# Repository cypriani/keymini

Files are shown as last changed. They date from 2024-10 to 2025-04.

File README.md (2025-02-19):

# Keymini, a minimalist ergonomic keyboard

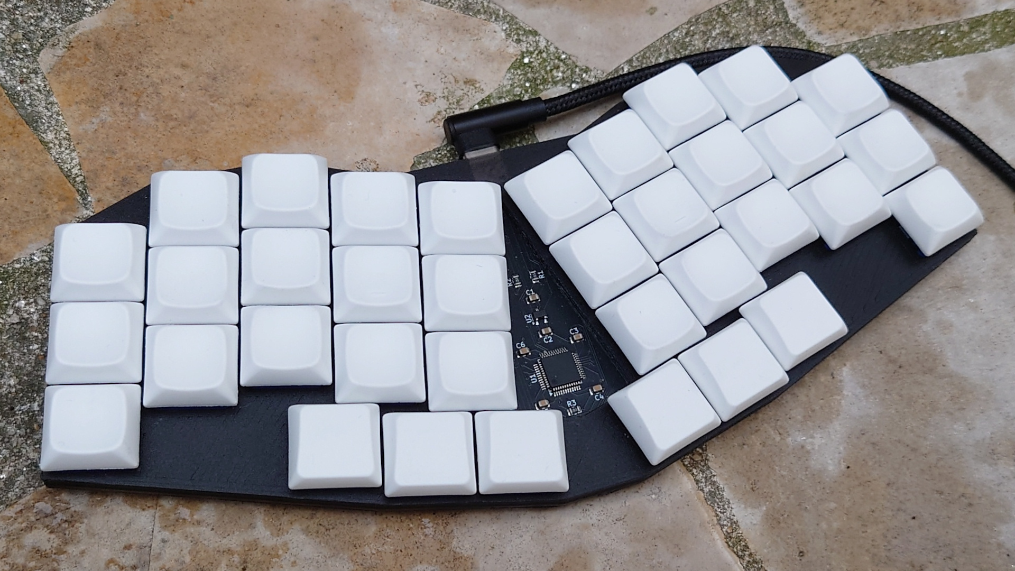
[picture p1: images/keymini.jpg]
Keymini


> Perfection is achieved, not when there is nothing more to add, but
> when there is nothing left to take away. ― Antoine de Saint-Exupéry

## Presentation

Keymini is a monoblock ergonomic keyboard with 36 keys. It is as low as
possible (with Kailh Choc v1 switches). As it is flat on the underside,
it can be used placed on a laptop keyboard, without actuating the
laptop keyboard keys.

Keymini is a minimalist keyboard in a lot of way:
* Only a keyboard, no LED, no rotary encoder, no screen, not split, no
  hotswap… Just USB-C connector and keys.
* Minimal size, entering in a C5/6 envelope (3 fold A4) or a Nintendo
  Switch Lite case.
* Minimal number of keys, at 36, as popularized by
  [Miryoku](https://github.com/manna-harbour/miryoku).
* Minimal keyspacing, following the classical "choc spacing."
* Minimal height, with the switch plate at 5.8 mm from the desk.
* Minimal number of component, with only 2 extended parts for PCB
  assembly by JLCPCB.
* Minimalistic style, with no decoration, simple hull countour.
* Minimalist license (MIT) for an opensource keyboard.

Inspirations:
* My previous designs, in particular
  [KeySeeBee](https://github.com/TeXitoi/keyseebee) for the components
  and the fat plate, and
  [Keyberon-f4](https://github.com/TeXitoi/keyberon-f4) for
  experiencing with the key placement and unibody shape.
* [Ferris](https://github.com/pierrechevalier83/ferris) for the
  stagger and the diode placement..
* [3W6](https://github.com/weteor/3W6) for the "too fat plate" design
  idea, and gluing something directly on the back of the PCB.

## Other pages to see

To see more photos, see the [gallery](GALLERY.md).

You can look at the [build guide](BUILDING.md), to see how it is
constructed, and to make your own!

For instructions on the PCB manufacturing, see the [gerbers
directory](pcb/gerbers/).

For information on building and flashing the firmware, see the
[firmware directory](firmware/).

For information on the default layout, see the [layout page](LAYOUT.md).

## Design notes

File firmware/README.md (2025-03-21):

# Keymini Rust firmware

Install the complete toolchain and utils:

```shell
curl https://sh.rustup.rs -sSf | sh
# restart terminal to update the environment
rustup target add thumbv6m-none-eabi
rustup component add llvm-tools-preview
cargo install cargo-binutils
sudo apt-get install dfu-util
```

Compile:

```shell
cd firmware
cargo objcopy --bin keymini --release -- -O binary firmware.bin
```

To flash using dfu-util, launch it with:
```shell
dfu-util -w -d 0483:df11 -a 0 -s 0x08000000:leave -D firmware.bin
```

Then, put the board in DFU mode by:
 * Putting the keyboard in DFU mode as defined in the firmware. By
   default, it’s the leftmost key on the function layer. So, press
   simultaneously the 2 middle thumb keys, and then tap the leftmost
   thumb key.
 * Or (for the first time, or in case of buggy firmware) by shorting
   the 2 pads under the board (with a piece of aluminium foil for
   example, pressing hard) and plug USB while doing the connection.

Upload should begin as soon as the computer detects the board in
DFU mode.

The first time, if the write fail, your flash might be protected. To
unprotect:

```shell
dfu-util -d 0483:df11 -a 0 -s 0x08000000:force:unprotect -D firmware.bin
```

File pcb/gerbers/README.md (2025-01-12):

# Instructions

Choose a version, go to the corresponding directory.

Go to [JLCPCB](https://jlcpcb.com/). Upload the zip file as "gerber
file". Choose the PCB color and surface finish. The other options
should be OK as default.

Activate PCB Assembly. Assemble top side, economic. Select "tooling
holes: added by JLCPCB. The other options should be OK as default.

Add "boom.csv" as BOM file and "keymini-top-pos.csv" as CLP file.

Check that the components are found and in stock. The USB-C connector
has a standard footprint, so another reference can be used. Also, you
can use a STM32F072C8T6 if the CB variant is not available (less
flash, but enough for a keyboard).

Check the position of the USB-C connector. Check the direction of the
diodes (the bar should be on the left). Check that the LDO (the 3 pin
chip) is correctly placed. Check that the MCU is correctly placed,
with the marked pin aligned with the mark on the silkscreen (bottom
left).

2024-11-04, I payed 63.62€ including tax and shipping to France using
"Global Standard Direct Line".

# Change log

## v0.2 (2025-01-12)

* add copper pur on the top
* remove SWD connector

Manufactured at JLCPCB. Fully fonctionnal. Some PCB are lightly
warped, some are perfectly flat.

## v0.1 (2024-11-04)

Manufactured SMT.

Sent to manufacturing at JLCPCB. Fully functionnal. The PCB are
warped, maybe because of the ground filling only on one side. This
warping makes an anoying balance of the keyboard when pushing on the
thumb keys. A workaround is to insert a spacer on the back between the
silicone sheet and the PCB under the BOOT connector.

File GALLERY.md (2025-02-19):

# Gallery

## v0.1, first prototype, gChoc switchs, ChocFox CFX keycaps, black PLA plate

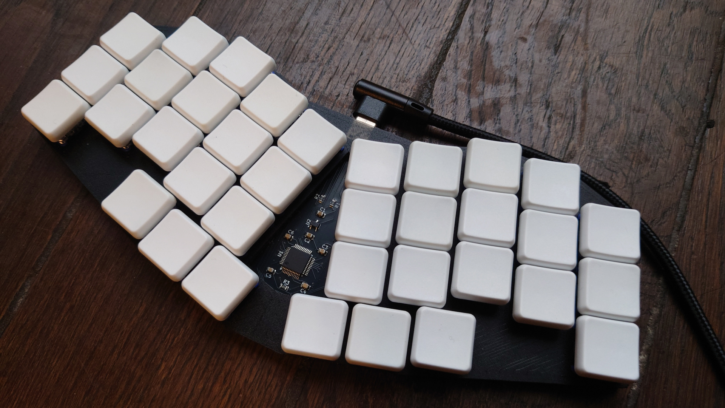
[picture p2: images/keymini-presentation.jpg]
presentation


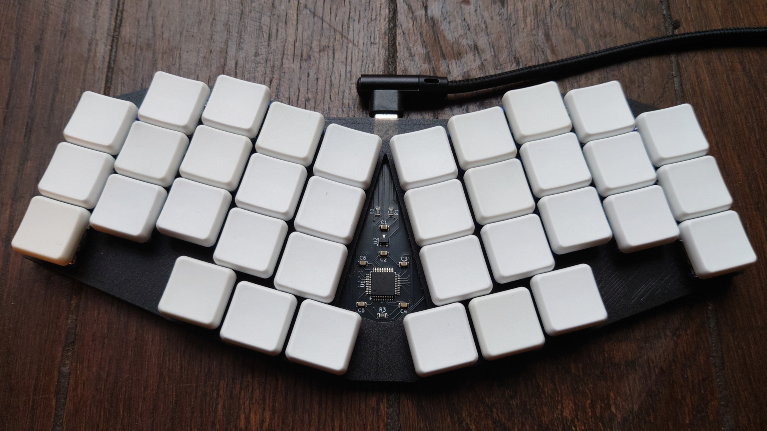
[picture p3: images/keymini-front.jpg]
front


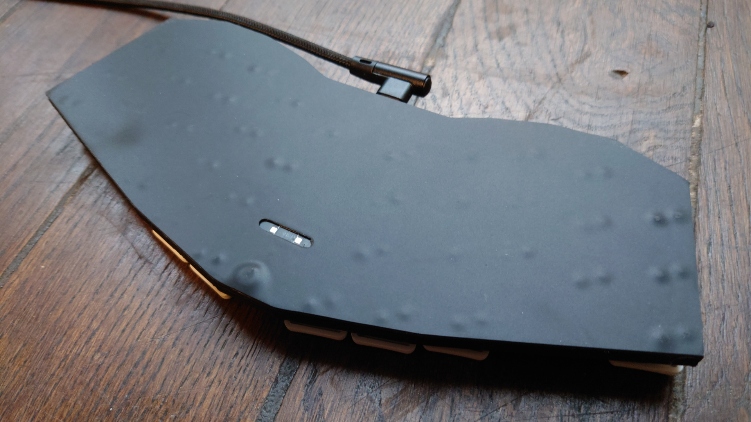
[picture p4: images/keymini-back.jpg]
back


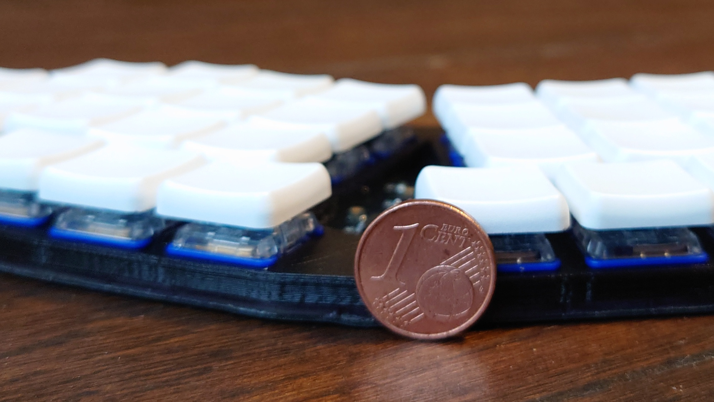
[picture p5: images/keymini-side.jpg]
side


## v0.1, Twilight switches, DDC keycaps, red PLA plate masking the components

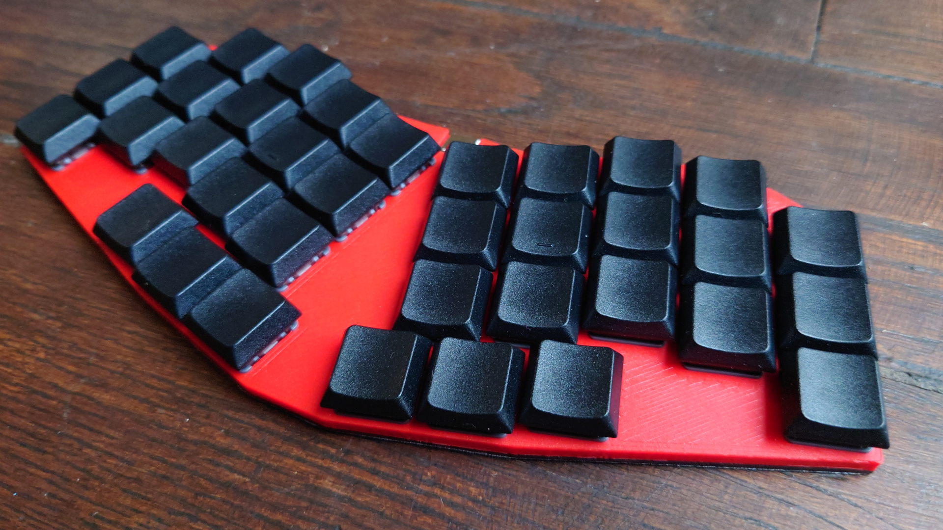
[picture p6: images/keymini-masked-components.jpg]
masked-components


## v0.2, Noctural switches, KLP Lamé normal on SLS nylon, colorless matte glazed oak plate

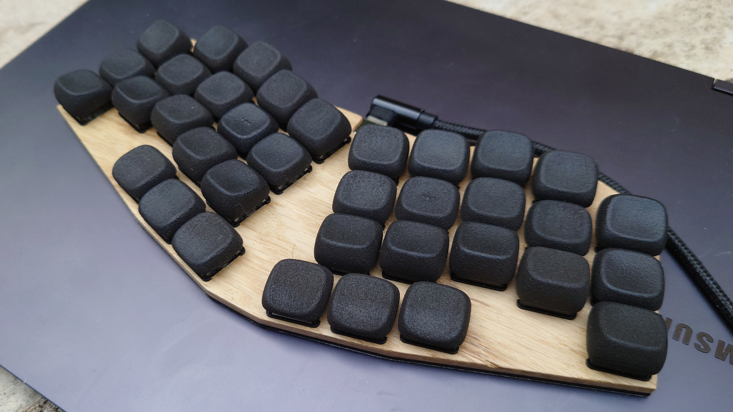
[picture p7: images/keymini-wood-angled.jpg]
angled


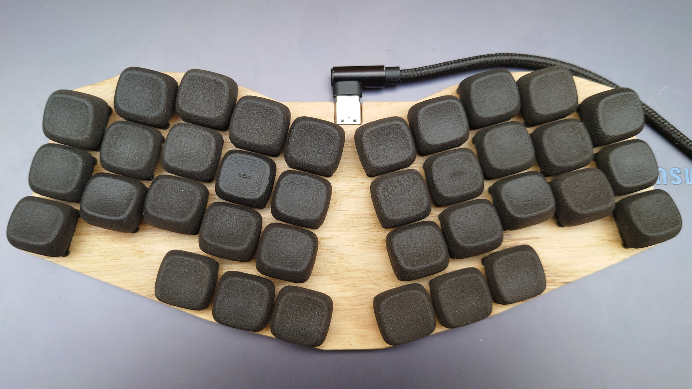
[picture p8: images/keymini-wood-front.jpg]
front


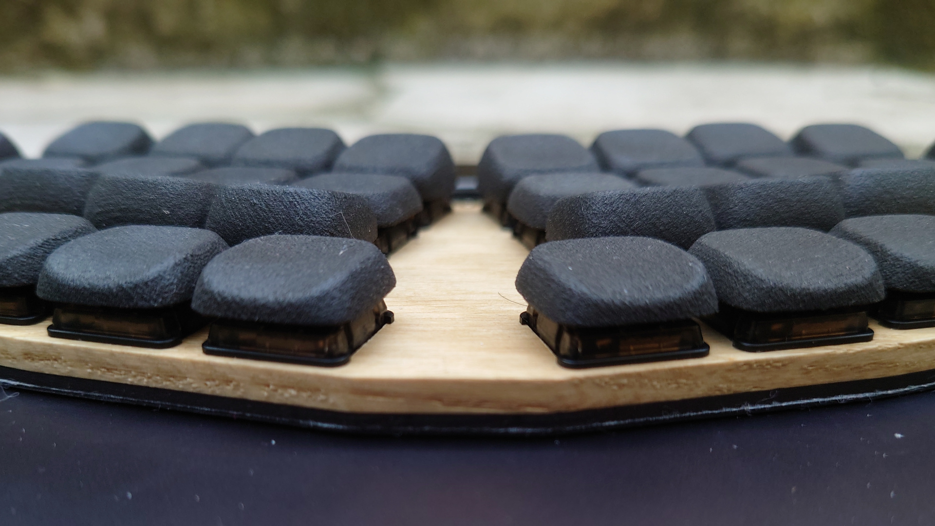
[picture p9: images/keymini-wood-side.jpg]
side


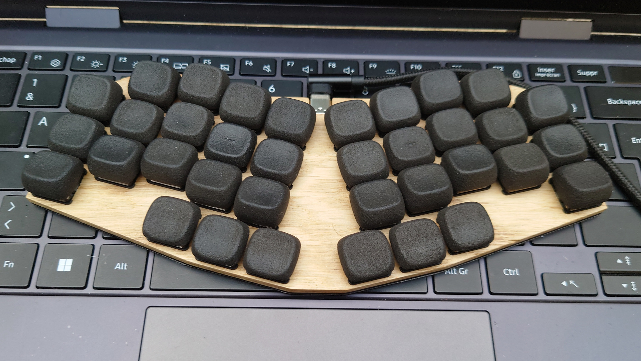
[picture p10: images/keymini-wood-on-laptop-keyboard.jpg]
on laptop keyboard


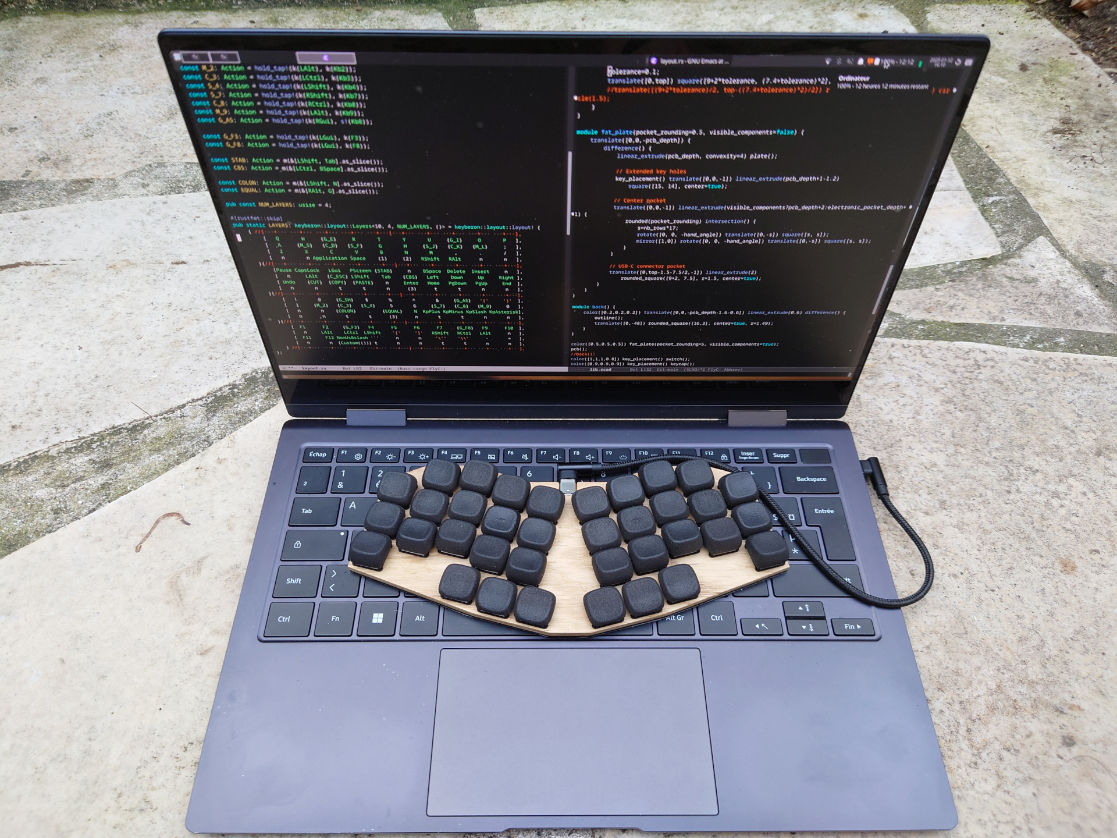
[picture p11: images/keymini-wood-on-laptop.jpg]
on laptop


## v0.2, Noctural switches, MBK keycaps, built by Louis

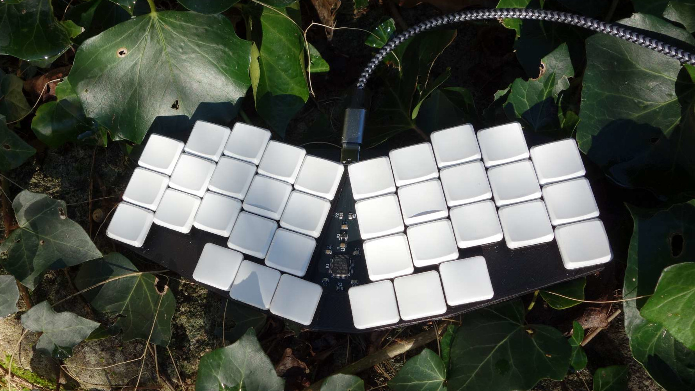
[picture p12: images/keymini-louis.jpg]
Louis’ Keymini


## v0.2, Noctural switches, LDSA keycaps, purple with alumine PLA plate

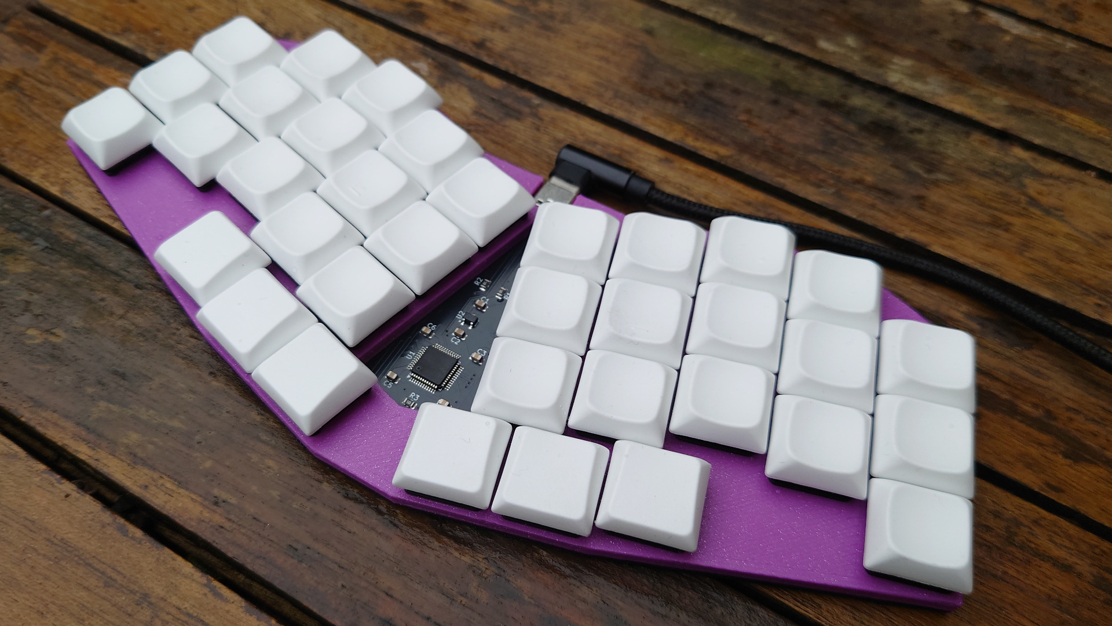
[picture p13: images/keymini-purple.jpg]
purple


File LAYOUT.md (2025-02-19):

# Layout

As of the time of writing, I use a 4 layer layout, and the
[ergo‑l](https://ergol.org) layout, that provide an optimized symbol
layer on AltGr, plus additional french characters on a custom dead key
(the 1DK, noted ★). So on the first layer, top right character are
accessible after typing ★, while bottom right characters are
accessible while pressing AltGr.

The Nav layer, accessible with the left radial thumb key, provides
navigation and editing functionalities. Notably, Enter is available on
this layer. The "special" keys, as Escape, Insert… are placed
logically corresponding to the alpha layer (Escape at E, Insert above
I…).

The Num layer, accessible with the right radial thumb key, privides the
num row on the home row, the shifted num row on the top row, and
numerical related symbols on the bottom row, placed in a similar
position than on the other layers.

Finally, the Function layer, accessible with the 2 radial thumb keys
pressed at the same time, provides the function keys.

Home Row Mods are available at the same place on all layers (except
the right part of the Nav layer, to not interfere with
navigation). Thanks to this, I don’t have to think about the order
between layers and mods, and cords them in practice.

Shift has its dedicated thumb key for typing text, and is also
available as home row mod for mods combos. GUI (the Windows key, that
I mainly use for window manager shortcuts) is on the 2 upper middle
finger keys, as they are not used with the other modifiers, except
Shift. Pinky doesn’t have HRM as it is unconfortable to maintain
pressed.

Of course, all of this is my layout, and I encourage you to tweek
yours. My main inspiration was
[Miryoku](https://github.com/manna-harbour/miryoku). Another great
resource is [Arsenik](https://github.com/OneDeadKey/arsenik).

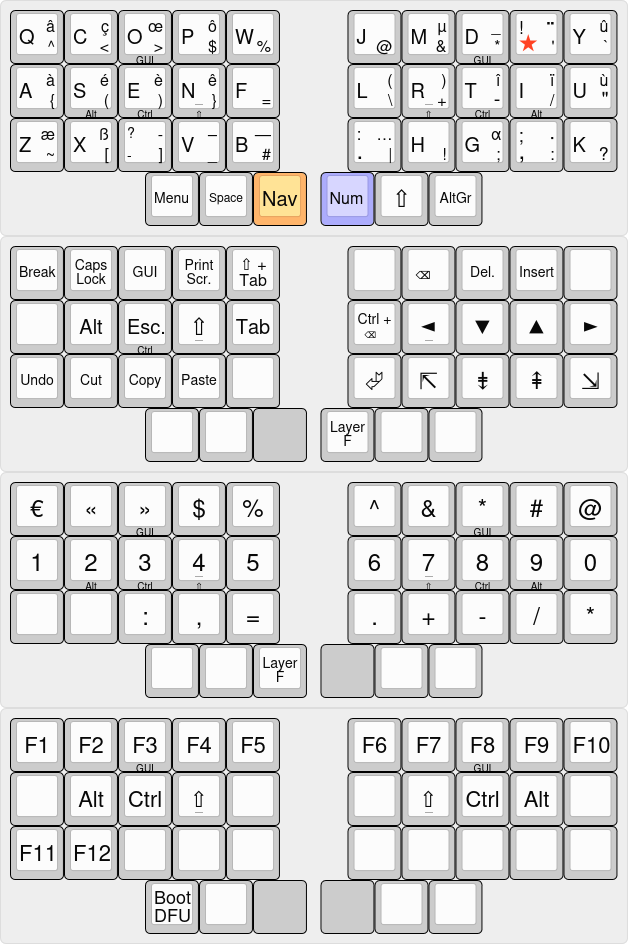
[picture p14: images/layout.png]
Layout


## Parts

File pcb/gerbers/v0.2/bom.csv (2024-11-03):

Designator | Footprint | Quantity | Designation | LCSC Part Number
C2,C1 | C_0805_2012Metric | 2 | 1µF | C28323
D2A1,D4D1,D2H1,D3H1,D4E1,D4G1,D2G1,D1I1,D2B1,D2F1,D3C1,D3B1,D1A1,D4C1,D1B1,D1C1,D1J1,D3E1,D3D1,D2E1,D1E1,D2I1,D1F1,D1H1,D3I1,D3J1,D2C1,D3F1,D2D1,D3G1,D3A1,D4H1,D2J1,D1D1,D4F1,D1G1 | D_SOD-323 | 36 | 1N4148WS | C2128
C4,C3,C6,C5 | C_0805_2012Metric | 4 | 100nF | C28233
R2,R1,R3 | R_0805_2012Metric | 3 | 5.1k | C27834
U1 | LQFP-48_7x7mm_P0.5mm | 1 | STM32F072CBT6 | C81720
J1 | USB_C_Receptacle_HRO_TYPE-C-31-M-12 | 1 | USB_C_Receptacle_USB2.0_16P | C165948
U2 | SOT-23-3 | 1 | XC6206P332MR | C5446

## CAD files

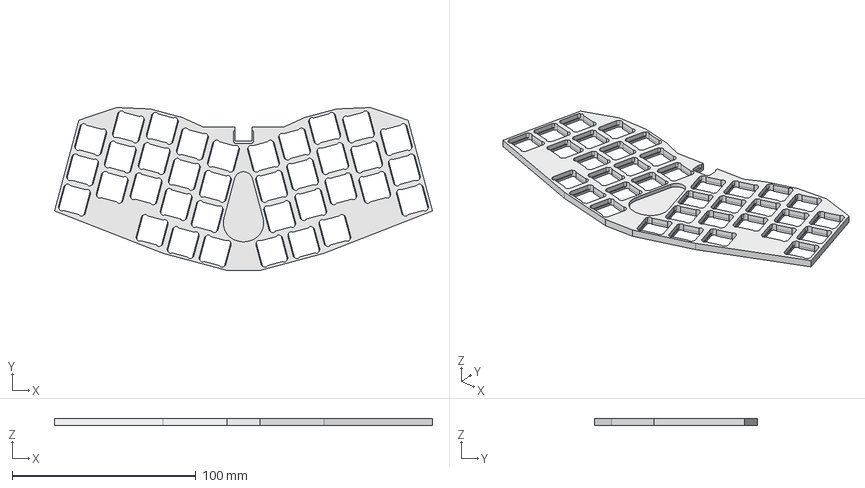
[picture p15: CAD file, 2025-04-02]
cad/fat_plate.FCStd
205.4 x 88.6 x 3.80 mm

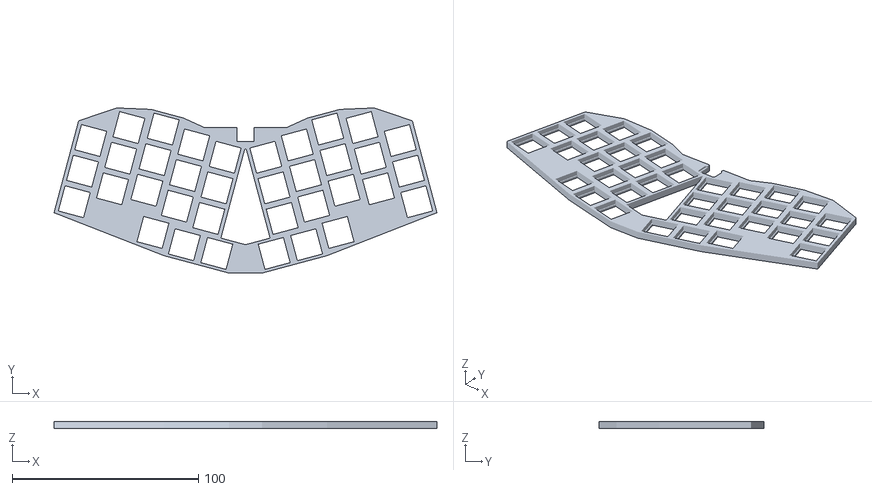
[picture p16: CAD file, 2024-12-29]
cad/fat_plate_visible_components.stl
205.4 x 88.6 x 3.80

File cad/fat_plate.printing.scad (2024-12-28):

use <lib.scad>;

rotate([0,180,0]) fat_plate(pocket_rounding=4);

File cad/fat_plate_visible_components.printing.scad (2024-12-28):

use <lib.scad>;

rotate([0,180,0]) fat_plate(visible_components=true);

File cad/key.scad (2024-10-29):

use <utils.scad>

module keycap() {
    translate([0,0,4]) hull() {
        linear_extrude(0.1) square([17.5, 16.5], center=true);
        translate([0, 0, 3]) linear_extrude(0.1) rounded_square(12, r=1.5, center=true);
    }
}

module switch() {
    translate([0,0,-2.2]) linear_extrude(3) rounded_square([13.5,13.5], r=1, center=true);
    linear_extrude(3, scale=0.8) rounded_square([15, 15], r=1, center=true);
    translate([0,0,-2.2-2.65]) cylinder(h=5, d=4);
}

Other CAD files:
cad/fat_plate-cnc_1.5mm.step
cad/plate.stl
cad/lib.scad
cad/fat_plate.stl
cad/plate.2d.scad
cad/plate.dxf
cad/utils.scad

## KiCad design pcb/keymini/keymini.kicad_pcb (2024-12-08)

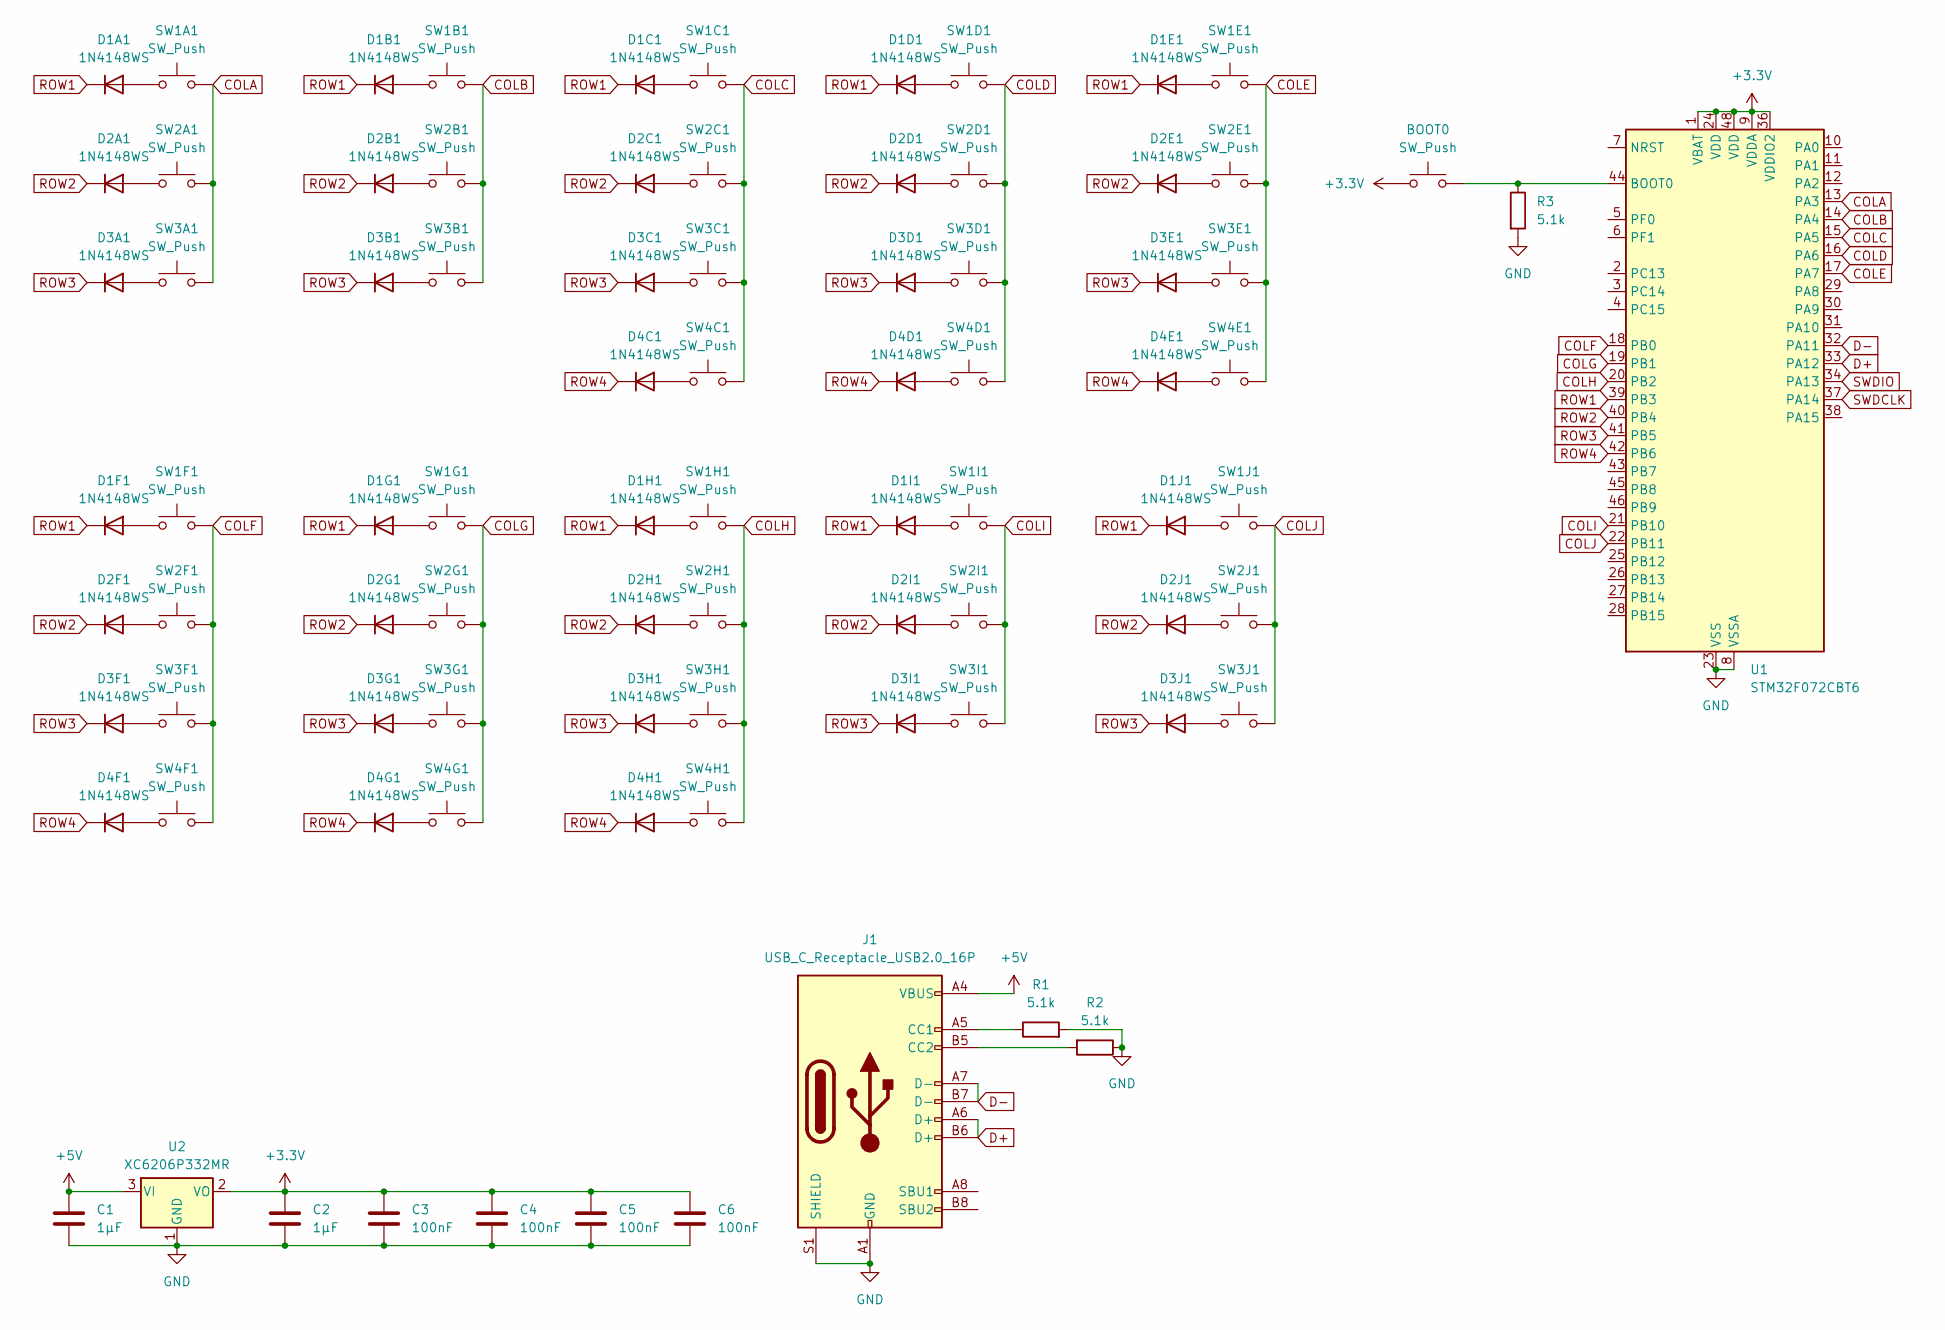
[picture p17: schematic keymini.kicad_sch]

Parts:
BOOT0: SW_Push; SW_SPST_CK_RS282G05A3
C1, C2: 1µF; C_0805_2012Metric
C3, C4, C5, C6: 100nF; C_0805_2012Metric
D1A1, D1B1, D1C1, D1D1, D1E1, D1F1, D1G1, D1H1, D1I1, D1J1, D2A1, D2B1, D2C1, D2D1, D2E1, D2F1, D2G1, D2H1, D2I1, D2J1, D3A1, D3B1, D3C1, D3D1, D3E1, D3F1, D3G1, D3H1, D3I1, D3J1, D4C1, D4D1, D4E1, D4F1, D4G1, D4H1: 1N4148WS; D_SOD-323
J1: USB_C_Receptacle_USB2.0_16P; USB_C_Receptacle_HRO_TYPE-C-31-M-12
R1, R2, R3: 5.1k; R_0805_2012Metric
SW1A1, SW1B1, SW1C1, SW1D1, SW1E1, SW1F1, SW1G1, SW1H1, SW1I1, SW1J1, SW2A1, SW2B1, SW2C1, SW2D1, SW2E1, SW2F1, SW2G1, SW2H1, SW2I1, SW2J1, SW3A1, SW3B1, SW3C1, SW3D1, SW3E1, SW3F1, SW3G1, SW3H1, SW3I1, SW3J1, SW4C1, SW4D1, SW4E1, SW4F1, SW4G1, SW4H1: SW_Push; SW_PG1350
U1: STM32F072CBT6; LQFP-48_7x7mm_P0.5mm
U2: XC6206P332MR; SOT-23-3

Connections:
+3.3V: BOOT0.1, C2.1, C3.1, C4.1, C5.1, C6.1, U1.1 (VBAT), U1.9 (VDDA), U1.24 (VDD), U1.36 (VDDIO2), U1.48 (VDD), U2.2 (VO)
+5V: C1.2, J1.A4 (VBUS), J1.A9 (VBUS), J1.B4 (VBUS), J1.B9 (VBUS), U2.3 (VI)
COLA: SW1A1.2, SW2A1.2, SW3A1.2, U1.13 (PA3)
COLB: SW1B1.2, SW2B1.2, SW3B1.2, U1.14 (PA4)
COLC: SW1C1.2, SW2C1.2, SW3C1.2, SW4C1.2, U1.15 (PA5)
COLD: SW1D1.2, SW2D1.2, SW3D1.2, SW4D1.2, U1.16 (PA6)
COLE: SW1E1.2, SW2E1.2, SW3E1.2, SW4E1.2, U1.17 (PA7)
COLF: SW1F1.2, SW2F1.2, SW3F1.2, SW4F1.2, U1.18 (PB0)
COLG: SW1G1.2, SW2G1.2, SW3G1.2, SW4G1.2, U1.19 (PB1)
COLH: SW1H1.2, SW2H1.2, SW3H1.2, SW4H1.2, U1.20 (PB2)
COLI: SW1I1.2, SW2I1.2, SW3I1.2, U1.21 (PB10)
COLJ: SW1J1.2, SW2J1.2, SW3J1.2, U1.22 (PB11)
D+: J1.A6 (D+), J1.B6 (D+), U1.33 (PA12)
D-: J1.A7 (D-), J1.B7 (D-), U1.32 (PA11)
GND: C1.1, C2.2, C3.2, C4.2, C5.2, C6.2, J1.A1 (GND), J1.A12 (GND), J1.B1 (GND), J1.B12 (GND), J1.S1 (SHIELD), R1.2, R2.1, R3.2, U1.8 (VSSA), U1.23 (VSS), U1.35 (VSS), U1.47 (VSS), U2.1 (GND)
unnamed: D1A1.2 (A), SW1A1.1
unnamed: D1B1.2 (A), SW1B1.1
unnamed: D1C1.2 (A), SW1C1.1
unnamed: D1D1.2 (A), SW1D1.1
unnamed: D1E1.2 (A), SW1E1.1
unnamed: D1F1.2 (A), SW1F1.1
unnamed: D1G1.2 (A), SW1G1.1
unnamed: D1H1.2 (A), SW1H1.1
unnamed: D1I1.2 (A), SW1I1.1
unnamed: D1J1.2 (A), SW1J1.1
unnamed: D2A1.2 (A), SW2A1.1
unnamed: D2B1.2 (A), SW2B1.1
unnamed: D2C1.2 (A), SW2C1.1
unnamed: D2D1.2 (A), SW2D1.1
unnamed: D2E1.2 (A), SW2E1.1
unnamed: D2F1.2 (A), SW2F1.1
unnamed: D2G1.2 (A), SW2G1.1
unnamed: D2H1.2 (A), SW2H1.1
unnamed: D2I1.2 (A), SW2I1.1
unnamed: D2J1.2 (A), SW2J1.1
unnamed: D3A1.2 (A), SW3A1.1
unnamed: D3B1.2 (A), SW3B1.1
unnamed: D3C1.2 (A), SW3C1.1
unnamed: D3D1.2 (A), SW3D1.1
unnamed: D3E1.2 (A), SW3E1.1
unnamed: D3F1.2 (A), SW3F1.1
unnamed: D3G1.2 (A), SW3G1.1
unnamed: D3H1.2 (A), SW3H1.1
unnamed: D3I1.2 (A), SW3I1.1
unnamed: D3J1.2 (A), SW3J1.1
unnamed: D4C1.2 (A), SW4C1.1
unnamed: D4D1.2 (A), SW4D1.1
unnamed: D4E1.2 (A), SW4E1.1
unnamed: D4F1.2 (A), SW4F1.1
unnamed: D4G1.2 (A), SW4G1.1
unnamed: D4H1.2 (A), SW4H1.1
unnamed: J1.A5 (CC1), R1.1
unnamed: J1.B5 (CC2), R2.2
unnamed: BOOT0.2, R3.1, U1.44 (BOOT0)
ROW1: D1A1.1 (K), D1B1.1 (K), D1C1.1 (K), D1D1.1 (K), D1E1.1 (K), D1F1.1 (K), D1G1.1 (K), D1H1.1 (K), D1I1.1 (K), D1J1.1 (K), U1.39 (PB3)
ROW2: D2A1.1 (K), D2B1.1 (K), D2C1.1 (K), D2D1.1 (K), D2E1.1 (K), D2F1.1 (K), D2G1.1 (K), D2H1.1 (K), D2I1.1 (K), D2J1.1 (K), U1.40 (PB4)
ROW3: D3A1.1 (K), D3B1.1 (K), D3C1.1 (K), D3D1.1 (K), D3E1.1 (K), D3F1.1 (K), D3G1.1 (K), D3H1.1 (K), D3I1.1 (K), D3J1.1 (K), U1.41 (PB5)
ROW4: D4C1.1 (K), D4D1.1 (K), D4E1.1 (K), D4F1.1 (K), D4G1.1 (K), D4H1.1 (K), U1.42 (PB6)
SWDCLK: U1.37 (PA14)
SWDIO: U1.34 (PA13)

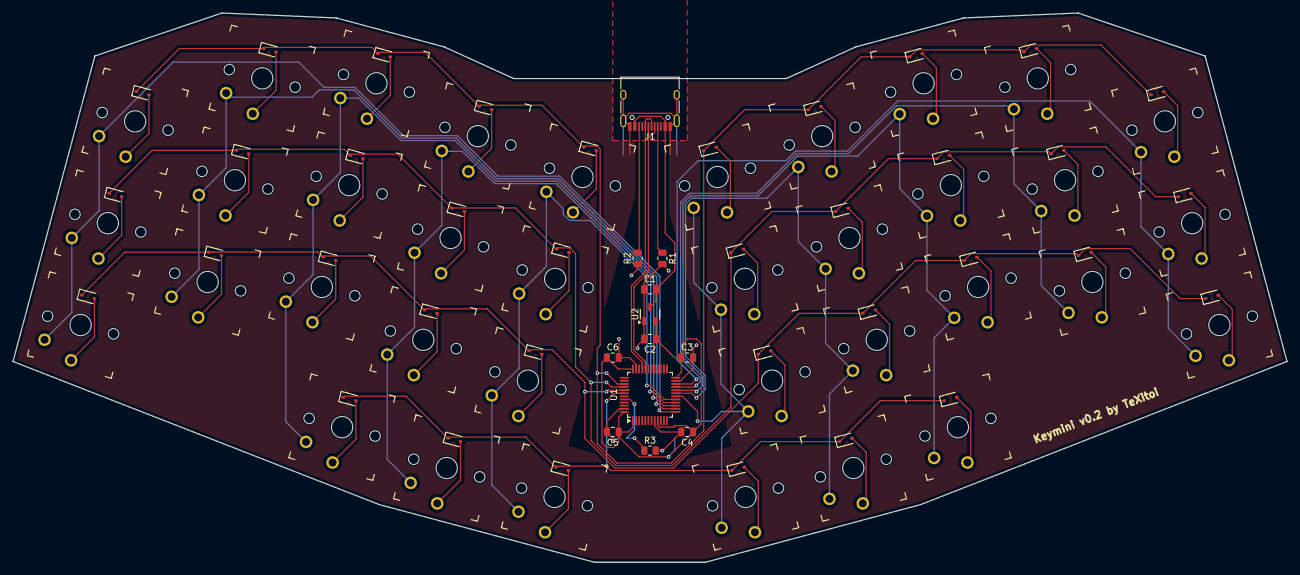
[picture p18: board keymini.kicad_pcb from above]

Board: 2 copper layers, 205.4 x 88.6 mm, 85 parts (1 on the bottom side), 58 nets.

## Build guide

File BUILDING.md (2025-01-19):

# Build guide

## Material

|Items |Quantity|
|---|---:|
|[Assembled PCB](pcb/gerbers/) | 1|
|[Fat plate](cad) | 1|
|[0.5mm self adhesive silicone sheet](https://www.aliexpress.com/item/1005003938672544.html) | 1|
|[Kailh Choc v1 switches](https://lowprokb.ca/collections/switches/products/ambients-silent-choc-switches)  | 36|
|[Choc spaced compatible keycaps](https://lowprokb.ca/collections/keycaps/products/ldsa-low-profile-blank-keycaps)|36|
|[USB-C cable](https://www.aliexpress.com/item/1005003058092715.html) | 1|
|[Solder Wire](https://www.aliexpress.com/item/1005007053733373.html) | 3g|
|Cardboard (as food packaging for example) | 20×10cm|
|Pure isopropyl alcohol or ethanol (optional) | 5mL|

|Tools                                                                                   |
|----------------------------------------------------------------------------------------|
|[Soldering kit](https://www.aliexpress.com/item/4000019437594.html)                     |
|[12mm×3mm hole punch](https://www.aliexpress.com/item/1005005796385084.html) (or bigger)|
|Hammer                                                                                  |
|Scissors                                                                                |
|Utility knife                                                                           |
|School glue stick                                                                       |
|A cutting board not afraid of the hole punch and the utility knife                      |
|Black permanent marker (optional)                                                       |
|approx 6mm hole punch (paper or leather, optional)                                      |

## Prepare the silicone sheet (WiP)

cardboard jig

cut silicone sheet in keyboard sized pieces

make hole

## Solder switches

Before doing anything with the PCB, flash it as explained at the
[firmware page](firmware/), and test the keys by shorting the contacts
on the PCB.

If you want, you can paint the border of the PCB with a black
permanent marker.

Inspect the back of the plate for any asperity. You can sand the back
of the plate with a knife to be sure that any small imperfection is
sanded.

Then, Place all the switches on the plate. They should be easy to
put. If some are a bit mobile, that’s not a problem. Be sure to put
all of them in the good direction (pins at the opposite of the USB
pocket), and that all the pins are straight.

The plate should not be too warped. If the switches are difficult to
clip, they can bend the plate. In this case, better to sand the holes
a bit.

Place gently the plate over the PCB, inserting the pins in the PCB
holes. Be sure that no pin bend. Press firmly, to be sure that
everything is well placed. The metal pins should be just at the level
of the PCB.

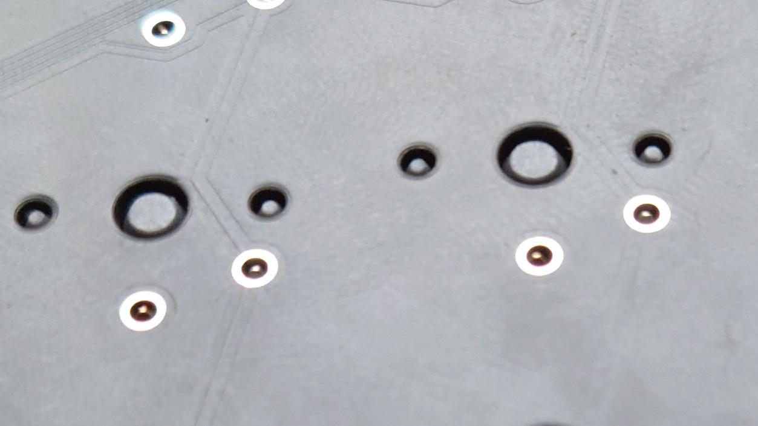
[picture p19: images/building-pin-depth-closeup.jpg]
Pins depth closeup


For the switches on the corners, solder ONE pin, then press firmly the
switch to the PCB while reflowing the solder. This is to be sure the
plate touches the PCB.

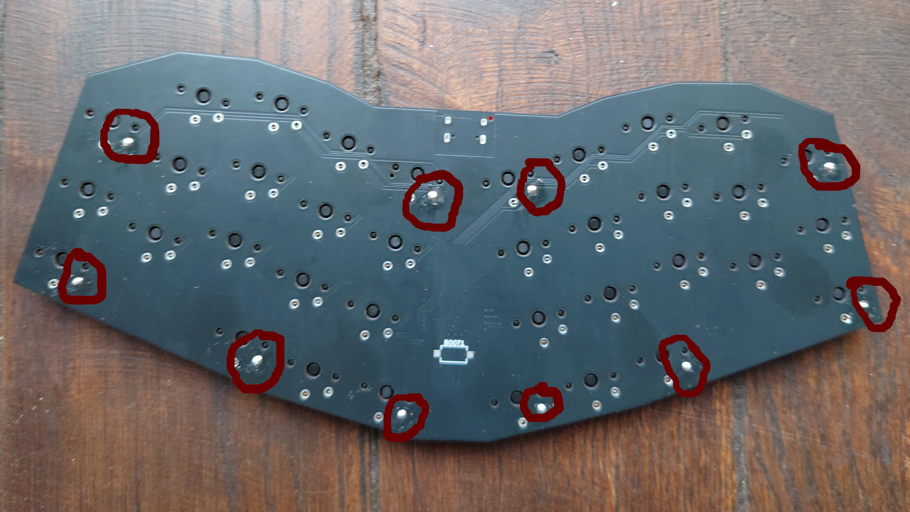
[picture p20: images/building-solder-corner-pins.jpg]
Corner pins to solder


Inspect that the plate touch the PCB on the sides. Repeat the
preceding procedure if it is not the case.

You can now solder all the pins. Be sure to put enough solder inside
the hole, and try to have a flush solder. You can remove excessive
solder with the soldering iron by capillarity. Ideally, the PCB should
be as flat as possible.

Test the keyboard, all the switches must be functional. If not, add
solder to the pins of the problematic pins, and stay 2 real seconds on
the solder to be sure the solder is well done.

Now that the soldering is finished, you can (but don’t need to) clean
the flux with IPA or another flux solvent. You can also use pure
ethanol, but don’t use acetone. Be careful to not put too much solvent
on the borders of the PCB or you might dissolve its painting (if you
have done it).

## Level the board

The PCB might not be completely flat, or the solder join might be a
bit high in some places. You don’t want your keyboard to be wobbly
while typing, so a bit of tuning is needed.

Put the soldered board on a flat surface (a desk for example). Press
on the empty space between the 2 thumb clusters. The board might move
a tiny bit.

Put a small disk of cardboard (done with the 6mm hole punch or with
scissors) between the PCB and the desk. It should be between the boot
connector and the edge of the PCB. Check, by repeating the previous
step, that the PCB doesn’t move anymore. Add as much as cardboard
circle as necessary. In case of doubt, better one more than one less.

On this photo, one layer was needed.

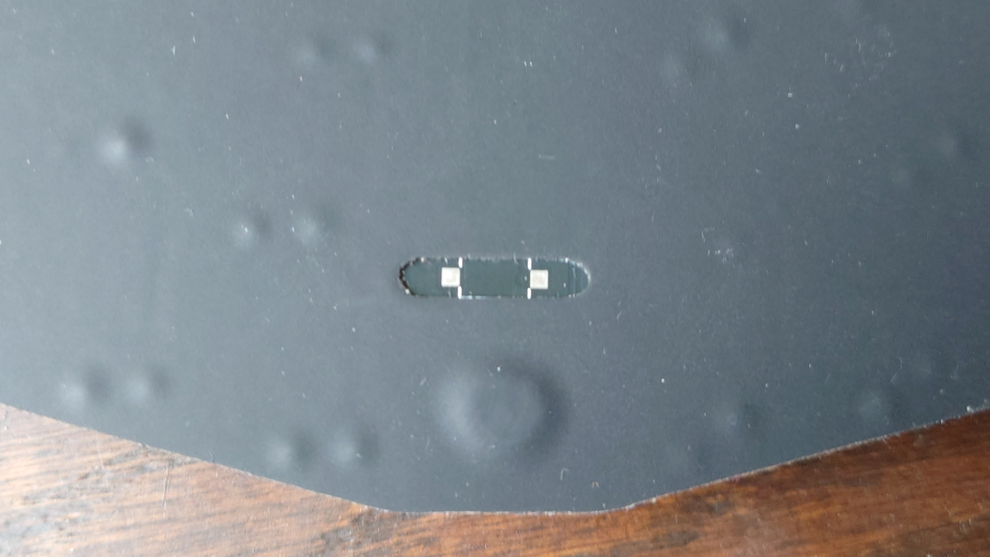
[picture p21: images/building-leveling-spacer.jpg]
Leveling spacer


## Glue the silicone sheet

First, glue the leveling spacers with some school glue stick together,
and on the PCB, between the BOOT connectors and the edge. The glue is
only to keep them in place during the next operation.

Remove the protection foil of the previously prepared adhesive
silicone sheet. Align the BOOT hole with the BOOT connector, being
careful to not move the spacer. Then, press firmly from the center to
the borders, to avoid any bubble, and glue the silicone sheet. Bubbles
like to stay around the spacer, so be conscientious in this area. On
the other areas, the bubbles disappear around the switches.

Put the keyboard on the cutting board, and cut the excess of silicone
sheet with the utility knife. The blade should be angled, parallel to
the edge, touching the PCB. Cut in 4 steps: one for the top, one
for each side, and one for the bottom.

Your keyboard is ready! Enjoy!

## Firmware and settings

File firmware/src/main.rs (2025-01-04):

#![no_main]
#![no_std]

// set the panic handler
use panic_halt as _;

use crate::layout::{LAYERS, NUM_LAYERS};
use core::convert::Infallible;
use core::mem::MaybeUninit;
use cortex_m::peripheral::SCB;
use hal::gpio::{Input, Output, Pin, PullUp, PushPull};
use hal::prelude::*;
use hal::usb;
use hal::{stm32, timers};
use keyberon::debounce::Debouncer;
use keyberon::key_code::KbHidReport;
use keyberon::layout::{CustomEvent, Layout};
use keyberon::matrix::Matrix;
use rtic::app;
use stm32f0xx_hal as hal;
use usb_device::bus::UsbBusAllocator;
use usb_device::class::UsbClass as _;
use usb_device::device::UsbDeviceState;

mod layout;

type UsbClass = keyberon::Class<'static, usb::UsbBusType, ()>;
type UsbDevice = usb_device::device::UsbDevice<'static, usb::UsbBusType>;

#[link_section = ".uninit.GOTO_BOOTLOADER"]
static mut GOTO_BOOTLOADER: MaybeUninit<u8> = MaybeUninit::uninit();
const GO: u8 = 60;

#[cortex_m_rt::pre_init]
unsafe fn maybe_jump_bootloader() {
    let software_reset = (*hal::pac::RCC::ptr()).csr.read().sftrstf().bit_is_set();
    let jump_bootloader = software_reset && GOTO_BOOTLOADER.assume_init() == GO;
    (*&raw mut GOTO_BOOTLOADER).write(0);
    if jump_bootloader {
        cortex_m::asm::bootload(0x1FFFC800 as _);
    }
}

pub fn bootloader() -> ! {
    unsafe { (*&raw mut GOTO_BOOTLOADER).write(GO) };
    SCB::sys_reset()
}

trait ResultExt<T> {
    fn get(self) -> T;
}
impl<T> ResultExt<T> for Result<T, Infallible> {
    fn get(self) -> T {
        match self {
            Ok(v) => v,
            Err(e) => match e {},
        }
    }
}

#[app(device = crate::hal::pac, peripherals = true, dispatchers = [CEC_CAN])]
mod app {
    use super::*;

    #[shared]
    struct Shared {
        usb_dev: UsbDevice,
        usb_class: UsbClass,
    }

    #[local]
    struct Local {
        matrix: Matrix<Pin<Input<PullUp>>, Pin<Output<PushPull>>, 10, 4>,
        debouncer: Debouncer<[[bool; 10]; 4]>,
        layout: Layout<10, 4, NUM_LAYERS, ()>,
        timer: timers::Timer<stm32::TIM3>,
    }

    #[init(local = [bus: Option<UsbBusAllocator<usb::UsbBusType>> = None])]
    fn init(mut c: init::Context) -> (Shared, Local, init::Monotonics) {
        let mut rcc = c
            .device
            .RCC
            .configure()
            .hsi48()
            .enable_crs(c.device.CRS)
            .sysclk(48.mhz())
            .pclk(24.mhz())
            .freeze(&mut c.device.FLASH);

        let gpioa = c.device.GPIOA.split(&mut rcc);
        let gpiob = c.device.GPIOB.split(&mut rcc);

        let usb = usb::Peripheral {
            usb: c.device.USB,
            pin_dm: gpioa.pa11,
            pin_dp: gpioa.pa12,
        };
        *c.local.bus = Some(usb::UsbBusType::new(usb));
        let usb_bus = c.local.bus.as_ref().unwrap();

        let usb_class = keyberon::new_class(usb_bus, ());
        let usb_dev = keyberon::new_device(usb_bus);

        let mut timer = timers::Timer::tim3(c.device.TIM3, 1.khz(), &mut rcc);
        timer.listen(timers::Event::TimeOut);

        let pa3 = gpioa.pa3;
        let pa4 = gpioa.pa4;
        let pa5 = gpioa.pa5;
        let pa6 = gpioa.pa6;
        let pa7 = gpioa.pa7;
        let Ok(matrix) = cortex_m::interrupt::free(move |cs| {
            Matrix::new(
                [
                    pa3.into_pull_up_input(cs).downgrade(),
                    pa4.into_pull_up_input(cs).downgrade(),
                    pa5.into_pull_up_input(cs).downgrade(),
                    pa6.into_pull_up_input(cs).downgrade(),
                    pa7.into_pull_up_input(cs).downgrade(),
                    gpiob.pb0.into_pull_up_input(cs).downgrade(),
                    gpiob.pb1.into_pull_up_input(cs).downgrade(),
                    gpiob.pb2.into_pull_up_input(cs).downgrade(),
                    gpiob.pb10.into_pull_up_input(cs).downgrade(),
                    gpiob.pb11.into_pull_up_input(cs).downgrade(),
                ],
                [
                    gpiob.pb3.into_push_pull_output(cs).downgrade(),
                    gpiob.pb4.into_push_pull_output(cs).downgrade(),
                    gpiob.pb5.into_push_pull_output(cs).downgrade(),
                    gpiob.pb6.into_push_pull_output(cs).downgrade(),
                ],
            )
        });

        (
            Shared { usb_dev, usb_class },
            Local {
                timer,
                debouncer: Debouncer::new([[false; 10]; 4], [[false; 10]; 4], 5),
                matrix: matrix,
                layout: Layout::new(&LAYERS),
            },
            init::Monotonics(),
        )
    }

    #[task(binds = USB, priority = 2, shared = [usb_dev, usb_class])]
    fn usb_rx(c: usb_rx::Context) {
        (c.shared.usb_dev, c.shared.usb_class).lock(|usb_dev, usb_class| {
            if usb_dev.poll(&mut [usb_class]) {
                usb_class.poll();
            }
        });
    }

    #[task(
        binds = TIM3,
        priority = 1,
        local = [matrix, debouncer, timer, layout],
        shared = [usb_dev, usb_class],
    )]
    fn tick(mut c: tick::Context) {
        let _ = c.local.timer.wait();

        for event in c.local.debouncer.events(c.local.matrix.get().get()) {
            c.local.layout.event(event)
        }

        match c.local.layout.tick() {
            CustomEvent::Release(()) => bootloader(),
            _ => (),
        }
        if c.shared.usb_dev.lock(|d| d.state()) != UsbDeviceState::Configured {
            return;
        }
        let report: KbHidReport = c.local.layout.keycodes().collect();
        if !c
            .shared
            .usb_class
            .lock(|k| k.device_mut().set_keyboard_report(report.clone()))
        {
            return;
        }
        while let Ok(0) = c.shared.usb_class.lock(|k| k.write(report.as_bytes())) {}
    }
}

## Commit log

2024-10-28 PCB schema
    [keymini.kicad_pcb, keymini.kicad_sch]
2024-10-28 begining of cad
    [lib.scad]
2024-10-29 more cad
    [key.scad, lib.scad, utils.scad]
2024-10-29 bigger tolerences
    [lib.scad]
2024-10-30 Switch placement
    [keymini.kicad_pcb]
2024-10-30 correct C legend placement
    [keymini.kicad_pcb]
2024-10-31 key placement corrections
    [key_placement.csv, keymini.kicad_pcb]
2024-10-31 A bit of diode placement
    [diode_placement.csv, keymini.kicad_pcb]
2024-10-31 more diode placement
    [diode_placement.csv, keymini.kicad_pcb]
2024-10-31 diode placement: all done
    [diode_placement.csv, keymini.kicad_pcb]
2024-10-31 composant placement
    [keymini.kicad_pcb, keymini.kicad_sch]
2024-10-31 rename switches and diodes
    [keymini.kicad_pcb, keymini.kicad_sch]
2024-10-31 diode check
    [diode_placement.csv]
2024-10-31 a lot of traces
    [keymini.kicad_pcb]
2024-10-31 rows and cols connected
    [keymini.kicad_pcb, keymini.kicad_sch]
2024-10-31 trace tweeks
    [keymini.kicad_pcb]
2024-11-01 component plate pocket + components on PCB
    [lib.scad, utils.scad]
2024-11-01 Add SWD connector
    [keymini.kicad_pcb, keymini.kicad_sch]
2024-11-01 complete rooting with swo and ground plate
    [keymini.kicad_pcb]
2024-11-01 correct usb-c port rounding
    [lib.scad]
2024-11-01 printable plate
    [lib.scad, plate.printing.scad, plate.stl]
2024-11-02 make PCB checker happy
    [keymini.kicad_pcb]
2024-11-03 parameter for usbc connector pocket
    [lib.scad]
2024-11-03 Add gerber
    [keymini-B_Cu.gbl, keymini-B_Mask.gbs, keymini-B_Paste.gbp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]
2024-11-03 bom and pos begining
    [keymini.kicad_pcb]
2024-11-03 bom and pos
    [bom.csv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]
2024-11-04 Correct switch placement
    [keymini-B_Cu.gbl, keymini-B_Mask.gbs, keymini-B_Paste.gbp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]
2024-11-04 update ground plate
    [keymini.kicad_pcb]
2024-11-11 Plate tunning
    [lib.scad, plate.printing.scad, plate.stl]
2024-11-19 plate tweeks
    [lib.scad, plate.stl]
2024-11-28 change usb-c pocket in the plate to a simple cut
    [lib.scad, plate.stl]
2024-12-07 Add copper ground pur on front
    [keymini.kicad_pcb]
2024-12-07 Remove SWD connector
    [keymini.kicad_pcb, keymini.kicad_sch]
2024-12-07 v0.2 gerber
    [bom.csv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]
2024-12-08 Remove swd pocker from plate
    [lib.scad, plate.stl]
2024-12-08 More precise non pour around the components
    [keymini-B_Cu.gbl, keymini-B_Mask.gbs, keymini-B_Paste.gbp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]
2024-12-17 Corrections on pcb/gerbers/README.md
2024-12-25 Add plate.svg
    [fat_plate.printing.scad, fat_plate.stl, lib.scad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]
2024-12-28 Add fat plate with visible components as STL
    [fat_plate.printing.scad, fat_plate.stl, fat_plate_visible_components.printing.scad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]
2024-12-29 CNC 1.5mm min rounding files
    [fat_plate-cnc_1.5mm.step, fat_plate.FCStd, fat_plate.stl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]
2024-12-29 Move dogbone
    [fat_plate-cnc_1.5mm.step, fat_plate.FCStd]
2024-12-31 Smaller component pocket
    [fat_plate-cnc_1.5mm.step, fat_plate.FCStd, lib.scad]
2025-01-01 smaller component pocket in the freecad version
    [fat_plate-cnc_1.5mm.step, fat_plate.FCStd]
2025-01-18 BUILDING: Solder switches
2025-01-19 Update BOM
2025-01-19 BUILDING: leveling the board
2025-01-23 GALLERY: add Louis’ Keymini
2025-04-02 Tweek usb-c pocket in CNC file
    [fat_plate-cnc_1.5mm.step, fat_plate.FCStd]
